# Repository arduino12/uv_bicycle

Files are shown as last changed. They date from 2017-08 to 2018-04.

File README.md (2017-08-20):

# UV Bicycle
This repository was created for a rotating laser array above circle colored with [photochromic](https://en.wikipedia.org/wiki/Photochromism) paint.
We were able to draw fading SMS messages on the circle from above by using the ultra violet lasers that activates the photochromatic dye for short periods of time.

The project was done for and in collaboration with the [Bloomfield Science Museum in Jerusalem](http://www.mada.org.il/en) that provided us with the hardware and photochromatic paint.
It was created to serve as a science exhibit that demonstrates the properties of photochromatic dyes.
The code is licensed with the MIT license so you are free to use the code for your own needs.

See the results: https://goo.gl/photos/oJwscTjsn2JnW7Ck9

## Repository Content
[/src/arduino_to_uv/](https://github.com/arduino12/uv_bicycle/tree/master/src/arduino_to_uv) - Arduino code for rotating led/laser array.

[/src/auto_cts/](https://github.com/arduino12/uv_bicycle/tree/master/src/auto_cts) - Arduino code for toggling CTS line to GSM module.

[/src/gsm_to_arduino/](https://github.com/arduino12/uv_bicycle/tree/master/src/gsm_to_arduino) - Pi main code for receiving logging and drawing the SMS messages. 

## Hardware



### Pi Side
* Raspberry pi 3 with two USB-UART converters, provide both power and communication to BT and GSM modules.
* Extra arduino is needed because of AI-A6 GSM module bug that sends garbage in uart if CTS is not toggled.

### Bicycle Side
* The laser driver is ULN2003 - 7 NPN transistors in a single package.

## Software
* Must clone [infra](https://github.com/arduino12/infra) near this repo clone.
* For Google Sheets logger, put the json keys file near this repo.
* Better to auto run it with systemctl and see logs with journalctl on pi.

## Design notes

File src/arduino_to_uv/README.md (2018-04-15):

# Arduino To Uv
Arduino code for rotating led/laser array.

## Files structure

[arduino_to_uv.ino](https://github.com/arduino12/uv_bicycle/tree/master/src/arduino_to_uv/arduino_to_uv.ino) - Main arduino code, draw timing constants.

[common.h](https://github.com/arduino12/uv_bicycle/tree/master/src/arduino_to_uv/common.h) - Common macros.

[fix_texts.h](https://github.com/arduino12/uv_bicycle/tree/master/src/arduino_to_uv/fix_texts.h) - Permanent text for screen saver, saved in flash.

[graphics.h](https://github.com/arduino12/uv_bicycle/tree/master/src/arduino_to_uv/graphics.h) - Lib for drawing text slice by slice with leds.

[heb_5x7.h](https://github.com/arduino12/uv_bicycle/tree/master/src/arduino_to_uv/heb_5x7.h) - Software generated file for english and hebrew font array, saved in flash.

[interactive_menu.h](https://github.com/arduino12/uv_bicycle/tree/master/src/arduino_to_uv/interactive_menu.h) - Main busy loop for commands handling and text drawing. 

[leds.h](https://github.com/arduino12/uv_bicycle/tree/master/src/arduino_to_uv/leds.h) - Abstraction for led / laser array drivers.

[utf8.h](https://github.com/arduino12/uv_bicycle/tree/master/src/arduino_to_uv/utf8.h) - utf8 and unicode conversation stuff.

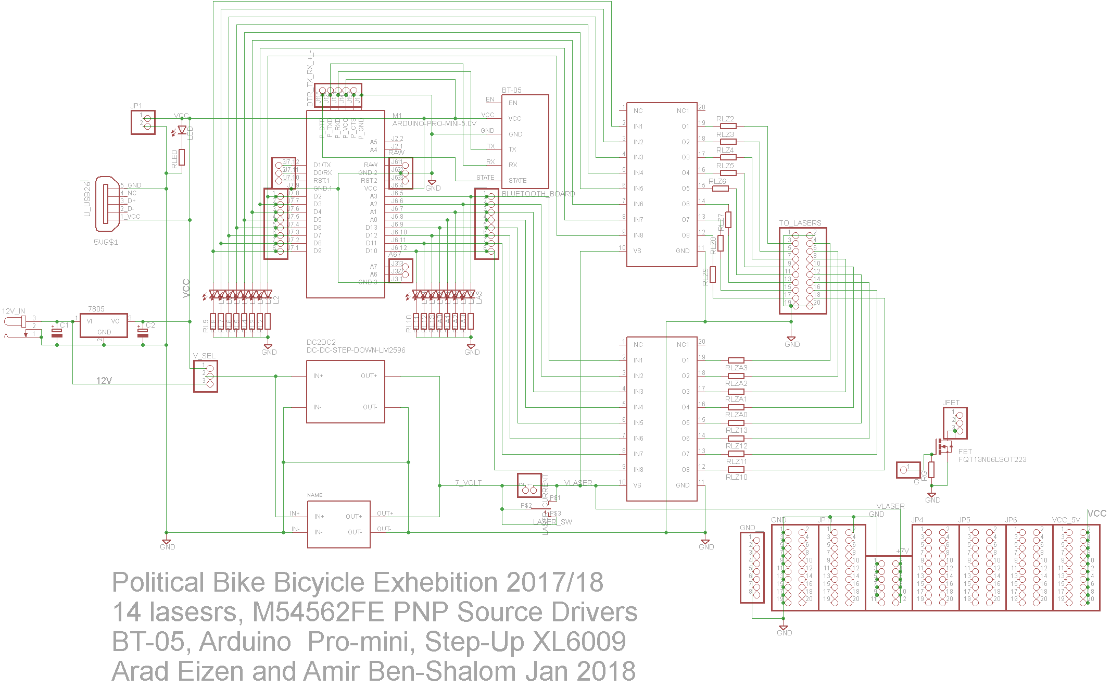
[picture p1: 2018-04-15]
pcb/V1/Politic_Bike_14_Laser_BT-05_Jan_2018_Sch.png

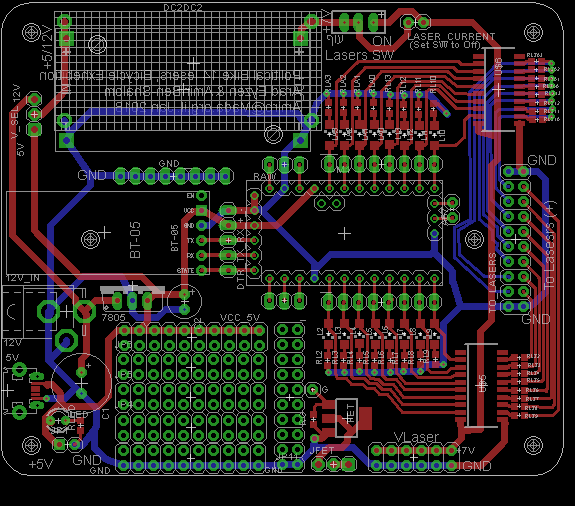
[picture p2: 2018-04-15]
pcb/V1/Politic_Bike_14_Laser_BT-05_Jan_2018_Brd.png

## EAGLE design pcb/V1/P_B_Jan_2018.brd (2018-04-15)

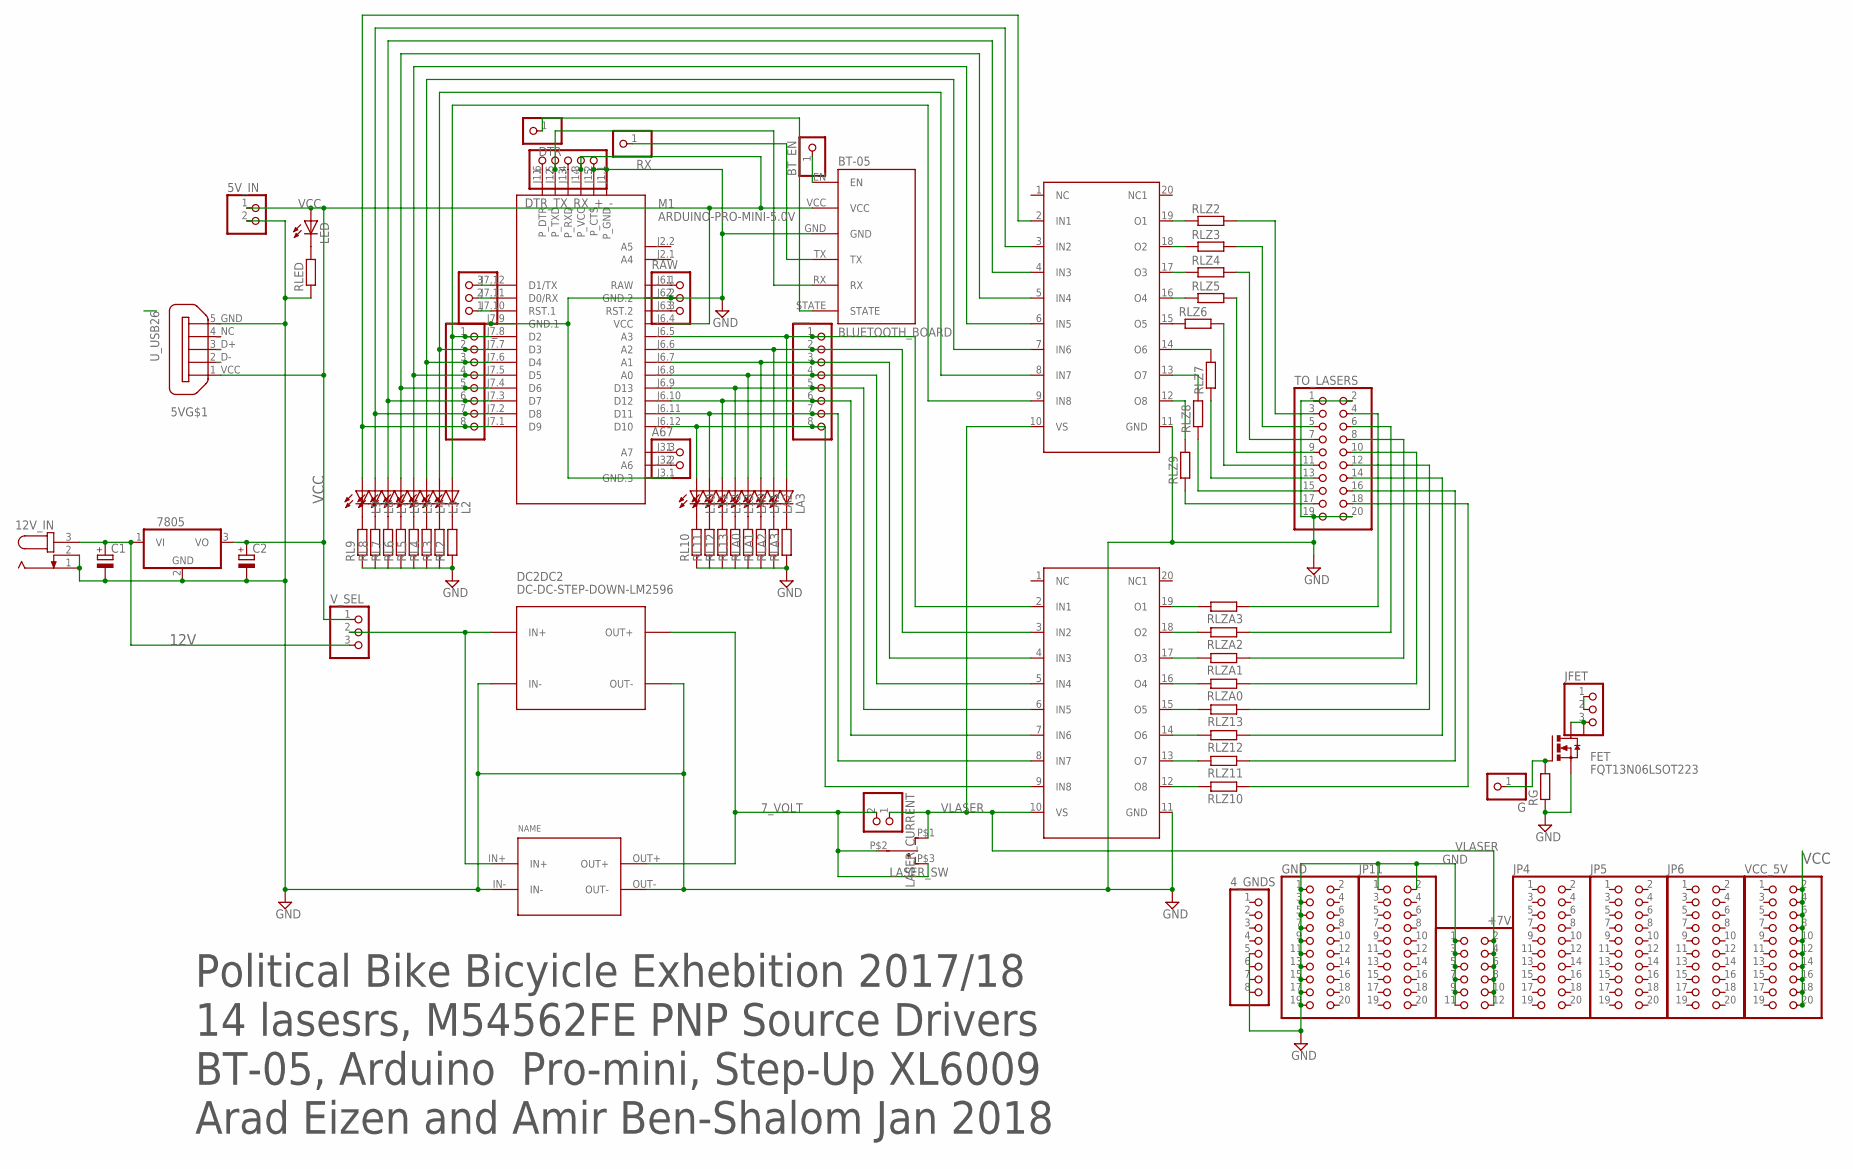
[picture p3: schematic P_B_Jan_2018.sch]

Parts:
4_GNDS: PINHD-1X8; 1X08
5V: U_USB26; U_USB_26
5V_IN: PINHD-1X2SQ&RND; 1X02_SQ&ROUND
12V_IN: JACK-PLUGHOLE_PAD; JACK_DC
7805: 7805TV; TO220V
+7V: PINHD-2X6; 2X06
A67: PINHD-1X2ROUND_PAD; 1X02_ROUND_PAD
BT-05: BLUETOOTH_BOARD; BT_BOARD_FOOTPRINT
BT_EN: PINHD-1X1; 1X01
C1: CPOL-EUE3.5-10; E3,5-10
C2: CPOL-EUE2.5-6; E2,5-6
DC2DC: DC2DC_CP8-ADJ; CP8-ADJ
DC2DC2: DC-DC-STEP-DOWN-LM2596
DTR: PINHD-1X1; 1X01
DTR_TX_RX_+_-: PINHD-1X5; 1X05
FET: FQT13N06LSOT223; SOT223
G: PINHD-1X1; 1X01
GND: PINHD-2X10; 2X10
JFET: PIN_HEAD_1X3_MARKED2.56; 1X3_MARKED
JP4, JP5, JP6, JP11: PINHD-2X10; 2X10
L2, L3, L4, L5, L6, L7, L8, L9, L10, L11, L12, L13: LEDCHIPLED_1206; CHIPLED_1206
LA0, LA1, LA2, LA3: LEDCHIPLED_1206; CHIPLED_1206
LASER_CURRENT: PINHD-1X2ROUND_PAD; 1X02_ROUND_PAD
LASER_SW: SW_SPDTSS_12D_00_W; SS_12D_00_W
LED: LED3MM
M1: ARDUINO-PRO-MINI-5.0V; ARDUINO-PRO-MINI
RAW: PINHD-1X3; 1X03
RG: R-EU_R0603; R0603
RL2, RL3, RL4, RL5, RL6, RL7, RL8, RL9, RL10, RL11, RL12, RL13: R-EU_R0603; R0603
RLA0, RLA1, RLA2, RLA3: R-EU_R0603; R0603
RLED: R-EU_R0603; R0603
RLZ2, RLZ3, RLZ4, RLZ5, RLZ6, RLZ7, RLZ8, RLZ9, RLZ10, RLZ11, RLZ12, RLZ13: R-EU_R0603; R0603
RLZA0, RLZA1, RLZA2, RLZA3: R-EU_R0603; R0603
RX: PINHD-1X1; 1X01
TO_LASERS: PINHD-2X10; 2X10
U$5, U$6: M54562P-SOP-20; P-SOP-20
VCC_5V: PINHD-2X10; 2X10
V_SEL: PIN_HEAD_1X3_MARKED2.56; 1X3_MARKED
_: PINHD-1X3; 1X03
__: PINHD-1X8; 1X08
___: PINHD-1X8; 1X08

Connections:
7_VOLT: DC2DC.OUT+, DC2DC2.OUT+, LASER_CURRENT.2, LASER_SW.P$2, LASER_SW.P$3 (S)
12V: 12V_IN.3, 7805.1 (VI), C1.+, V_SEL.3
A0: LA0.A, M1.J6.8 (A0), U$6.5 (IN4), ___.4
A1: LA1.A, M1.J6.7 (A1), U$6.4 (IN3), ___.3
A2: LA2.A, M1.J6.6 (A2), U$6.3 (IN2), ___.2
A3: LA3.A, M1.J6.5 (A3), U$6.2 (IN1), ___.1
D10: L10.A, M1.J6.12 (D10), U$6.9 (IN8), ___.8
D11: L11.A, M1.J6.11 (D11), U$6.8 (IN7), ___.7
D12: L12.A, M1.J6.10 (D12), U$6.7 (IN6), ___.6
D13: L13.A, M1.J6.9 (D13), U$6.6 (IN5), ___.5
GND: 4_GNDS.5, 4_GNDS.6, 4_GNDS.7, 4_GNDS.8, 5V.5_GND, 5V_IN.2, 12V_IN.1, 12V_IN.2, 7805.2 (GND), +7V.1, +7V.3, +7V.5, +7V.7, +7V.9, +7V.11, BT-05.GND, C1.-, C2.-, DC2DC.IN-, DC2DC.OUT-, DC2DC2.IN-, DC2DC2.OUT-, DTR_TX_RX_+_-.5, FET.3 (S), GND.1, GND.3, GND.5, GND.7, GND.9, GND.11, GND.13, GND.15, GND.17, GND.19, JP11.1, JP11.2, M1.J1.1 (P_GND), M1.J1.2 (P_CTS), M1.J3.1 (GND.3), M1.J6.2 (GND.2), M1.J7.9 (GND.1), RAW.2, RG.1, RL2.1, RL3.1, RL4.1, RL5.1, RL6.1, RL7.1, RL8.1, RL9.1, RL10.1, RL11.1, RL12.1, RL13.1, RLA0.1, RLA1.1, RLA2.1, RLA3.1, RLED.1, TO_LASERS.1, TO_LASERS.2, TO_LASERS.19, TO_LASERS.20, U$5.11 (GND), U$6.11 (GND)
unnamed: RLZ2.2, TO_LASERS.3
unnamed: RLZ3.2, TO_LASERS.5
unnamed: RLZ4.2, TO_LASERS.7
unnamed: RLZ5.2, TO_LASERS.9
unnamed: RLZ6.2, TO_LASERS.11
unnamed: RLZ7.1, TO_LASERS.13
unnamed: RLZ8.1, TO_LASERS.15
unnamed: RLZ9.1, TO_LASERS.17
unnamed: RLZA3.1, TO_LASERS.4
unnamed: RLZA2.1, TO_LASERS.6
unnamed: L3.A, M1.J7.7 (D3), U$5.8 (IN7), __.2
unnamed: L4.A, M1.J7.6 (D4), U$5.7 (IN6), __.3
unnamed: L5.A, M1.J7.5 (D5), U$5.6 (IN5), __.4
unnamed: L6.A, M1.J7.4 (D6), U$5.5 (IN4), __.5
unnamed: L7.A, M1.J7.3 (D7), U$5.4 (IN3), __.6
unnamed: L8.A, M1.J7.2 (D8), U$5.3 (IN2), __.7
unnamed: L9.A, M1.J7.1 (D9), U$5.2 (IN1), __.8
unnamed: L2.A, M1.J7.8 (D2), U$5.9 (IN8), __.1
unnamed: RLZA1.1, TO_LASERS.8
unnamed: RLZA0.1, TO_LASERS.10
unnamed: RLZ13.1, TO_LASERS.12
unnamed: RLZ12.1, TO_LASERS.14
unnamed: RLZ11.1, TO_LASERS.16
unnamed: RLZ10.1, TO_LASERS.18
unnamed: RLZ3.1, U$5.18 (O2)
unnamed: RLZ4.1, U$5.17 (O3)
unnamed: BT-05.STATE, DTR.1
unnamed: BT-05.RX, DTR_TX_RX_+_-.2, M1.J1.5 (P_TXD)
unnamed: BT-05.TX, RX.1
unnamed: RLZ2.1, U$5.19 (O1)
unnamed: RLZ5.1, U$5.16 (O4)
unnamed: RLZ6.1, U$5.15 (O5)
unnamed: RLZ7.2, U$5.14 (O6)
unnamed: RLZ8.2, U$5.13 (O7)
unnamed: RLZ9.2, U$5.12 (O8)
unnamed: RLZ10.2, U$6.12 (O8)
unnamed: RLZ11.2, U$6.13 (O7)
unnamed: RLZ12.2, U$6.14 (O6)
unnamed: RLZ13.2, U$6.15 (O5)
unnamed: RLZA0.2, U$6.16 (O4)
unnamed: RLZA1.2, U$6.17 (O3)
unnamed: RLZA2.2, U$6.18 (O2)
unnamed: RLZA3.2, U$6.19 (O1)
unnamed: L2.C, RL2.2
unnamed: L3.C, RL3.2
unnamed: L4.C, RL4.2
unnamed: L5.C, RL5.2
unnamed: L6.C, RL6.2
unnamed: L7.C, RL7.2
unnamed: L8.C, RL8.2
unnamed: L9.C, RL9.2
unnamed: LED.K (C), RLED.2
unnamed: M1.J7.10 (RST.1), _.1
unnamed: DC2DC.IN+, DC2DC2.IN+, V_SEL.2
unnamed: M1.J7.11 (D0/RX), _.2
unnamed: M1.J7.12 (D1/TX), _.3
unnamed: A67.1, M1.J3.3 (A7)
unnamed: A67.2, M1.J3.2 (A6)
unnamed: LA3.C, RLA3.2
unnamed: LA2.C, RLA2.2
unnamed: LA1.C, RLA1.2
unnamed: LA0.C, RLA0.2
unnamed: L13.C, RL13.2
unnamed: L12.C, RL12.2
unnamed: L11.C, RL11.2
unnamed: L10.C, RL10.2
unnamed: M1.J6.1 (RAW), RAW.1
unnamed: M1.J6.3 (RST.2), RAW.3
unnamed: FET.1 (G), G.1, RG.2
unnamed: JFET.1, JFET.2
unnamed: DTR_TX_RX_+_-.3, M1.J1.4 (P_RXD)
unnamed: DTR_TX_RX_+_-.1, M1.J1.6 (P_DTR)
unnamed: FET.2 (D), FET.4 (D1), JFET.3
unnamed: BT-05.EN, BT_EN.1
VCC: 5V.1_VCC (1_VDD), 5V_IN.1, 7805.3 (VO), BT-05.VCC, C2.+, DTR_TX_RX_+_-.4, LED.A, M1.J1.3 (P_VCC), M1.J6.4 (VCC), VCC_5V.2, VCC_5V.4, VCC_5V.6, VCC_5V.8, VCC_5V.10, VCC_5V.12, VCC_5V.14, VCC_5V.16, VCC_5V.18, VCC_5V.20, V_SEL.1
VLASER: +7V.2, +7V.4, +7V.6, +7V.8, +7V.10, +7V.12, LASER_CURRENT.1, LASER_SW.P$1 (O), U$5.10 (VS), U$6.10 (VS)

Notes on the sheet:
Political Bike Bicyicle Exhebition 2017/18 14 lasesrs, M54562FE PNP Source Drivers BT-05, Arduino Pro-mini, Step-Up XL6009 Arad Eizen and Amir Ben-Shalom Jan 2018

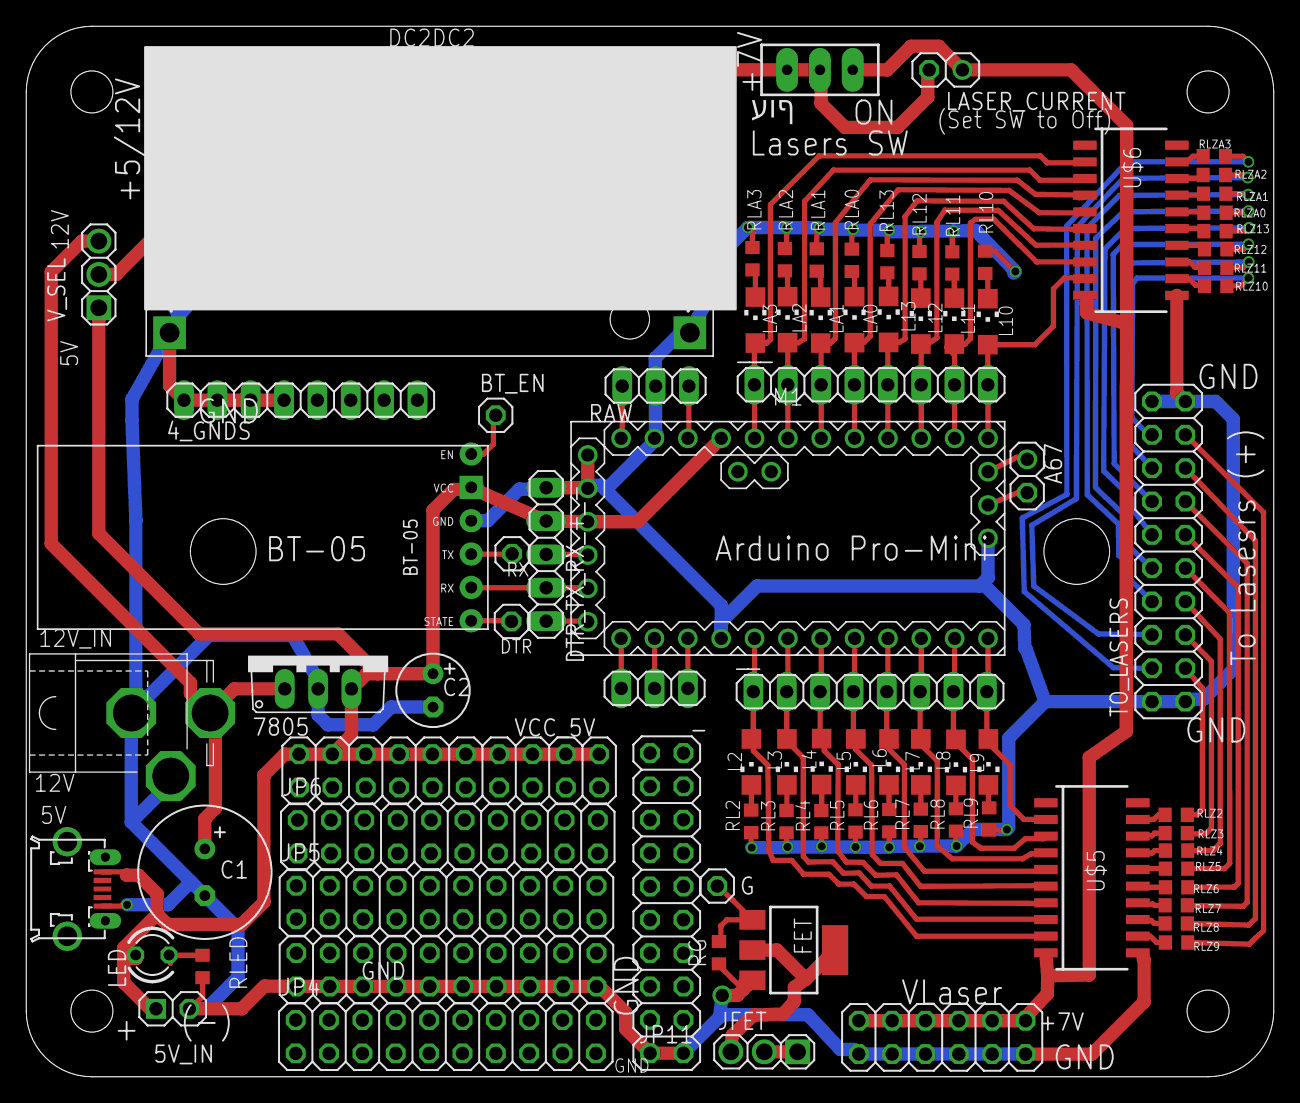
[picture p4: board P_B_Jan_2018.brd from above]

Board: 2 copper layers, 95.0 x 80.0 mm, 87 parts (0 on the bottom side), 87 nets.

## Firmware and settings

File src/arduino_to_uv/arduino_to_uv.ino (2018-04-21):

/*
 * Arduino code for rotating led/laser array.
 */

/* 0=7_lasers, 1=14_lasers */
#define HARDWARE_VERSION	(1)
/* uart baud rate in bit per seconds */
#define SERIAL_BAUD_RATE	(115200)
/* set uart read timeout in milliseconds */
#define SERIAL_TIMEOUT		(1)

#if HARDWARE_VERSION == 0
	#define GRAPHICS_FONT	(heb_5x7)
	#include "heb_5x7.h"
	/* 0=hebrew, 1=german */
	#define LANGUAGE_CODE		(0)
	/* default characters draw diraction bitmask GRAPHICS_RIGHT_TO_LEFT=1, GRAPHICS_TOP_TO_BOTTOM=2*/
	#define DRAW_DIRACTION		(GRAPHICS_RIGHT_TO_LEFT)
	/* turn on leds slice milliseconds (vertical pixels) */
	#define SLICE_ON_MS			(70)
	/* turn off leds milliseconds after each slice is draw */
	#define SLICE_OFF_MS		(0)
	/* turn off leds milliseconds after each char is draw */
	#define CHAR_OFF_MS			(90)
#else
	#define GRAPHICS_FONT	(heb_ger_11x13)
	#include "heb_ger_11x13.h"
	#define LANGUAGE_CODE		(1)
	#define DRAW_DIRACTION		(0)
	#define SLICE_ON_MS			(50)
	#define SLICE_OFF_MS		(0)
	#define CHAR_OFF_MS			(70)
#endif

#include "leds.h"
#include "graphics.h"
#include "interactive_menu.h"


void setup()
{
	Serial.begin(SERIAL_BAUD_RATE);
	Serial.setTimeout(SERIAL_TIMEOUT);
	leds_init();
	graphics_set_font(GRAPHICS_FONT);
	graphics_set_draw(SLICE_ON_MS, SLICE_OFF_MS, CHAR_OFF_MS, DRAW_DIRACTION);
	print_help();
}

void loop()
{
	interactive_menu_update();
}

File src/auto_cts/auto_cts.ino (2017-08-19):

/* auto_cts.ino
	Pull cts line high when uart communication is detected, so uart data will be bufferd.
	Then pull cts line low and ignore uart communication, so all the bufferd uart data will be sent at once */

#define SERIAL_CTS_PIN				(2)
#define SERIAL_CTS_ON_MS			(100)
#define SERIAL_CTS_OFF_MS			(50)
#define SERIAL_BAUDRATE				(115200)
#define SERIAL_BAUDRATE_PRESCALE	(F_CPU / 16 / SERIAL_BAUDRATE - 1)


/* flag to indicate uart communication */
volatile bool rx_detected = false;;


ISR(USART_RX_vect){
	/* must read UDR0 to clear interrupt */
    uint8_t rx_data = UDR0;
    rx_detected = true;
}

void setup() {
	/* set cts line as output */
	pinMode(LED_BUILTIN, OUTPUT);
	pinMode(SERIAL_CTS_PIN, OUTPUT);
	digitalWrite(LED_BUILTIN, LOW);
	digitalWrite(SERIAL_CTS_PIN, LOW);
	/* disable global interrupts */
	cli();
	/* set uart baudrate */
    UBRR0L = SERIAL_BAUDRATE_PRESCALE & 0xFF;
    UBRR0H = SERIAL_BAUDRATE_PRESCALE >> 8;
	/* enable uart rx interrupt */
    UCSR0B = _BV(RXCIE0) | _BV(RXEN0);
	/* set uart config: 8 data bits (no parity bit, 1 stop bit) */
    UCSR0C = _BV(UCSZ00) | _BV(UCSZ01);
	/* enable global interrupts */
	sei();
}

void loop() {
	uint8_t state = 0;
	uint32_t cur_ms;
	uint32_t state_ms;
	
	while (true) {
		cur_ms = millis();

		switch (state) {
			case 0: /* idle state: wait for uart communication */
				if (rx_detected) {
					digitalWrite(SERIAL_CTS_PIN, HIGH);
					digitalWrite(LED_BUILTIN, HIGH);
					state_ms = cur_ms + SERIAL_CTS_ON_MS;
					state = 1;
				}
			break;
			case 1: /* cts state: wait befor pulling cts line low */
				if (cur_ms > state_ms) {
					digitalWrite(SERIAL_CTS_PIN, LOW);
					state_ms = cur_ms + SERIAL_CTS_OFF_MS;
					state = 2;
				}
			break;
			case 2: /* ignore state: allow uart communication befor going back to idle state */
				if (cur_ms > state_ms) {
					digitalWrite(LED_BUILTIN, LOW);
					rx_detected = false;
					state = 0;
				}
			break;
		}
	}
}

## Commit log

2017-07-03 add uv_bicycle docs and src!
    [bt_modules_config.txt]
2017-07-05 fix to use FETs
    [leds.h]
2017-07-05 improve doc
    [bt_modules_config.txt]
2017-07-09 fix arduino code
2017-08-20 fix httplib2 cache bug in windows
    [constants.py, gsm_to_arduino.py]
2017-08-22 fix utf8 bug, and limit message size to 40 unicode chars
    [constants.py, interactive_menu.h]
2017-11-23 replace M590 with SIM800
    [constants.py, gsm_to_arduino.py]
2017-11-23 Move from 7 to 14 lasers, add german font
2017-12-21 fix email to picture logic
    [gsm_to_arduino.py]
2018-04-15 change arduino code pin mapping and more
2018-04-15 add pcb
    [P_B_Jan_2018.brd, P_B_Jan_2018.sch]
